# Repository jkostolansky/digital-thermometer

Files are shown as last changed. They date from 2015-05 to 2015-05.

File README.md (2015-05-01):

Digital Thermometer
===================

Digital Thermometer is an Arduino-based thermometer. It uses the DS18B20 1-Wire sensor.

Repository Contents
-------------------

* **/schematics**
    * **/schematics/eagle** - Eagle schematics and PCB layout
    * **/schematics/images** - Images of schematics and PCB layout
* **/digital_thermometer** - Arduino source code

The Beer-Ware License
---------------------

Juraj Kostolanský (@jkostolansky) wrote this file. As long as you retain this notice you can do whatever you want with this stuff. If we meet some day, and you think this stuff is worth it, you can buy me a beer in return.

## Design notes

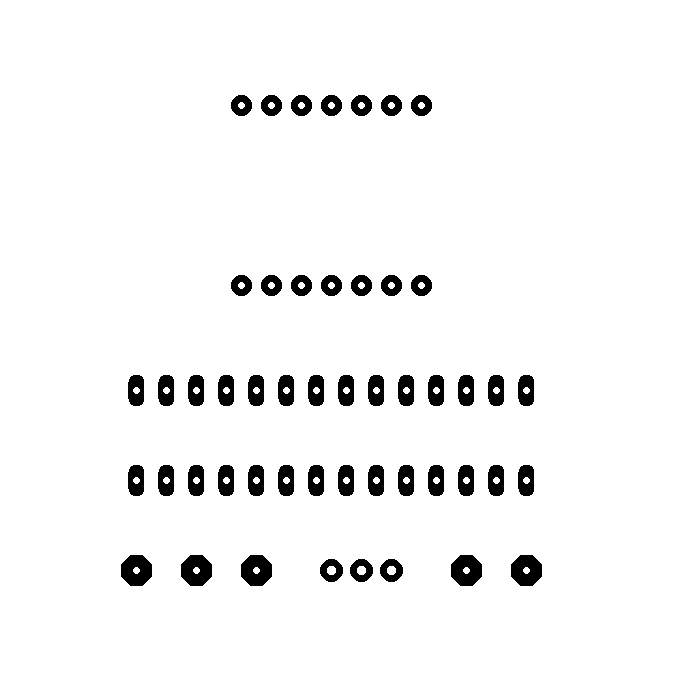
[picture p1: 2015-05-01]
schematics/images/pcb_mask.png

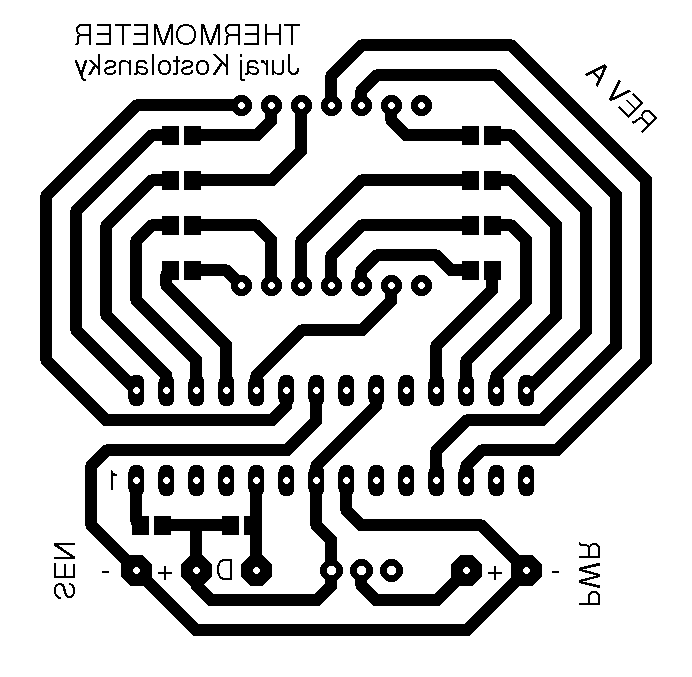
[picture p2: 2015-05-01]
schematics/images/pcb.png

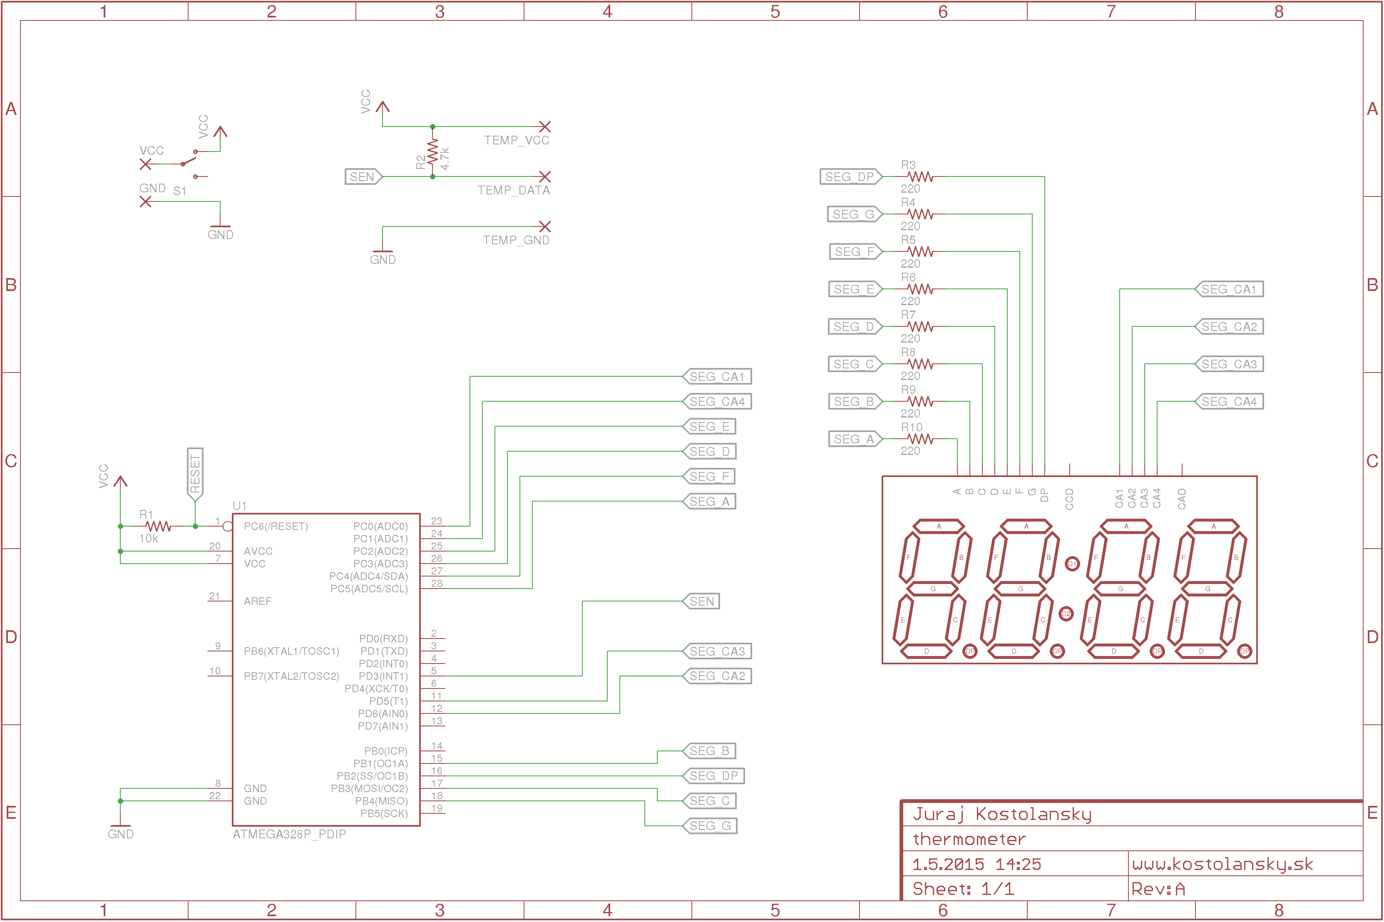
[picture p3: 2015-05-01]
schematics/images/schematic.png

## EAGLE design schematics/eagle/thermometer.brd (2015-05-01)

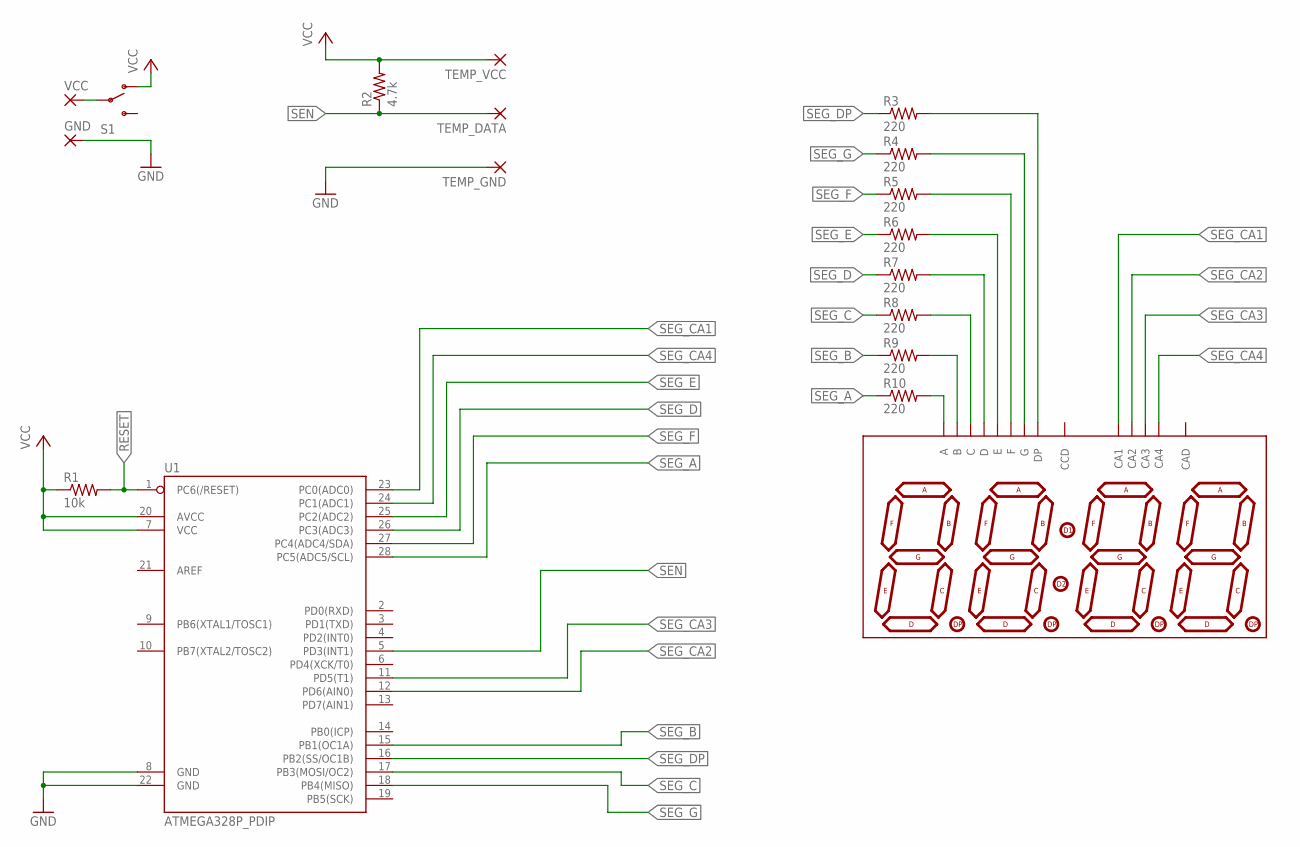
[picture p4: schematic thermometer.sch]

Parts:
GND: 2,54/0,8
R1: 10k; R0805
R2: 4.7k; R0805
R3, R4, R5, R6, R7, R8, R9, R10: 220; R0805
S1: SWITCH-SPDTPTH; SWITCH-SPDT
TEMP_DATA: 2,54/0,8
TEMP_GND: 2,54/0,8
TEMP_VCC: 2,54/0,8
U1: ATMEGA328P_PDIP; DIL28-3
U2: 5461BSDIP14; 5461BS
VCC: 2,54/0,8

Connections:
GND: GND.1, TEMP_GND.1, U1.8 (GND), U1.22 (GND)
unnamed: R10.2, U2.A
unnamed: R9.2, U2.B
unnamed: R7.2, U2.D
unnamed: R8.2, U2.C
unnamed: R6.2, U2.E
unnamed: R5.2, U2.F
unnamed: R4.2, U2.G
unnamed: R3.2, U2.DP
unnamed: S1.2, VCC.1
RESET: R1.2, U1.1 (PC6(/RESET))
SEG_A: R10.1, U1.28 (PC5(ADC5/SCL))
SEG_B: R9.1, U1.15 (PB1(OC1A))
SEG_C: R8.1, U1.17 (PB3(MOSI/OC2))
SEG_CA1: U1.23 (PC0(ADC0)), U2.CA1
SEG_CA2: U1.12 (PD6(AIN0)), U2.CA2
SEG_CA3: U1.11 (PD5(T1)), U2.CA3
SEG_CA4: U1.24 (PC1(ADC1)), U2.CA4
SEG_D: R7.1, U1.26 (PC3(ADC3))
SEG_DP: R3.1, U1.16 (PB2(SS/OC1B))
SEG_E: R6.1, U1.25 (PC2(ADC2))
SEG_F: R5.1, U1.27 (PC4(ADC4/SDA))
SEG_G: R4.1, U1.18 (PB4(MISO))
SEN: R2.1, TEMP_DATA.1, U1.5 (PD3(INT1))
VCC: R1.1, R2.2, S1.1 (O), TEMP_VCC.1, U1.7 (VCC), U1.20 (AVCC)

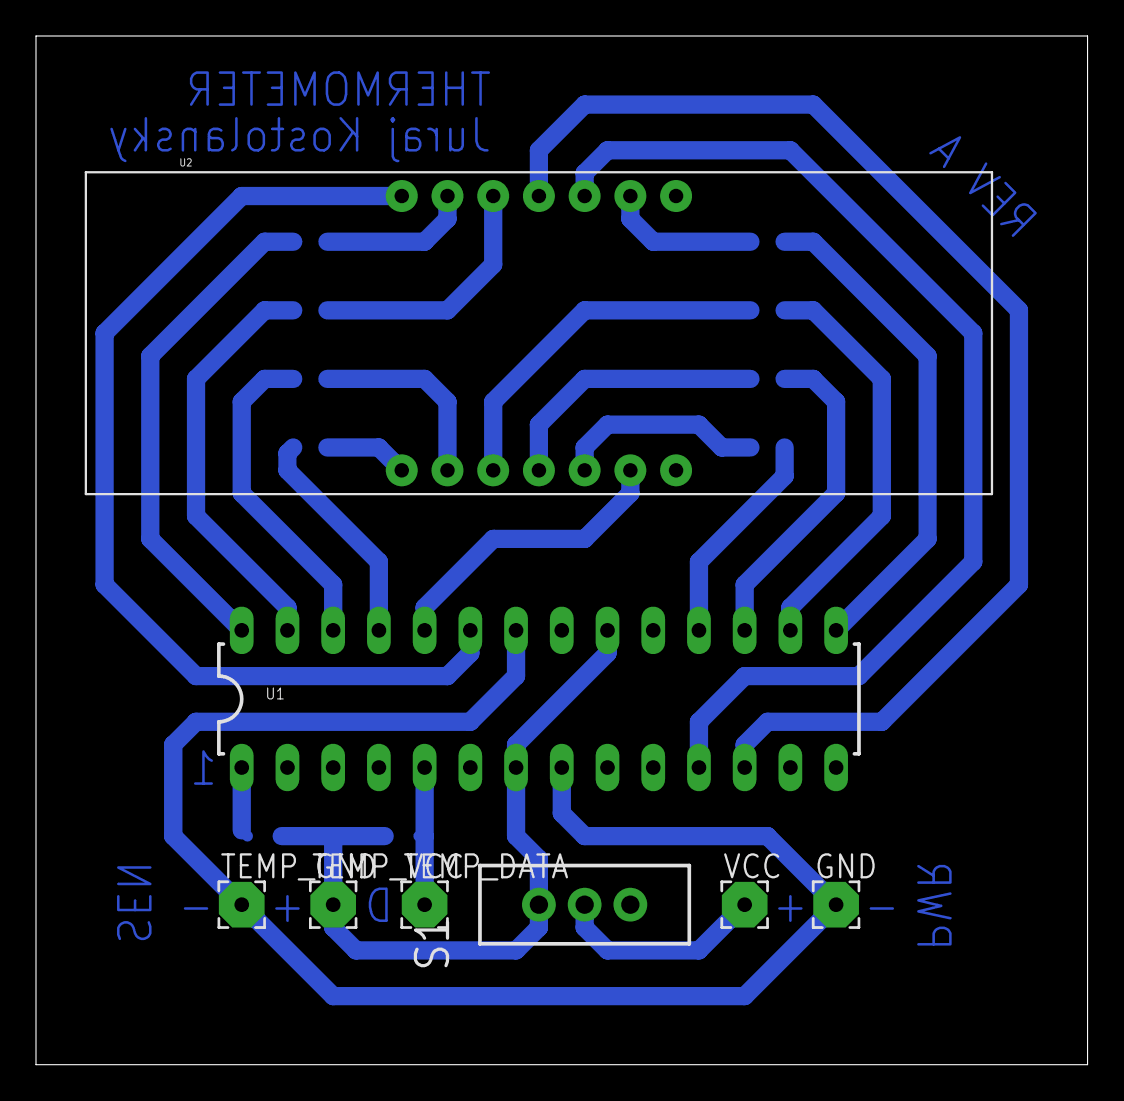
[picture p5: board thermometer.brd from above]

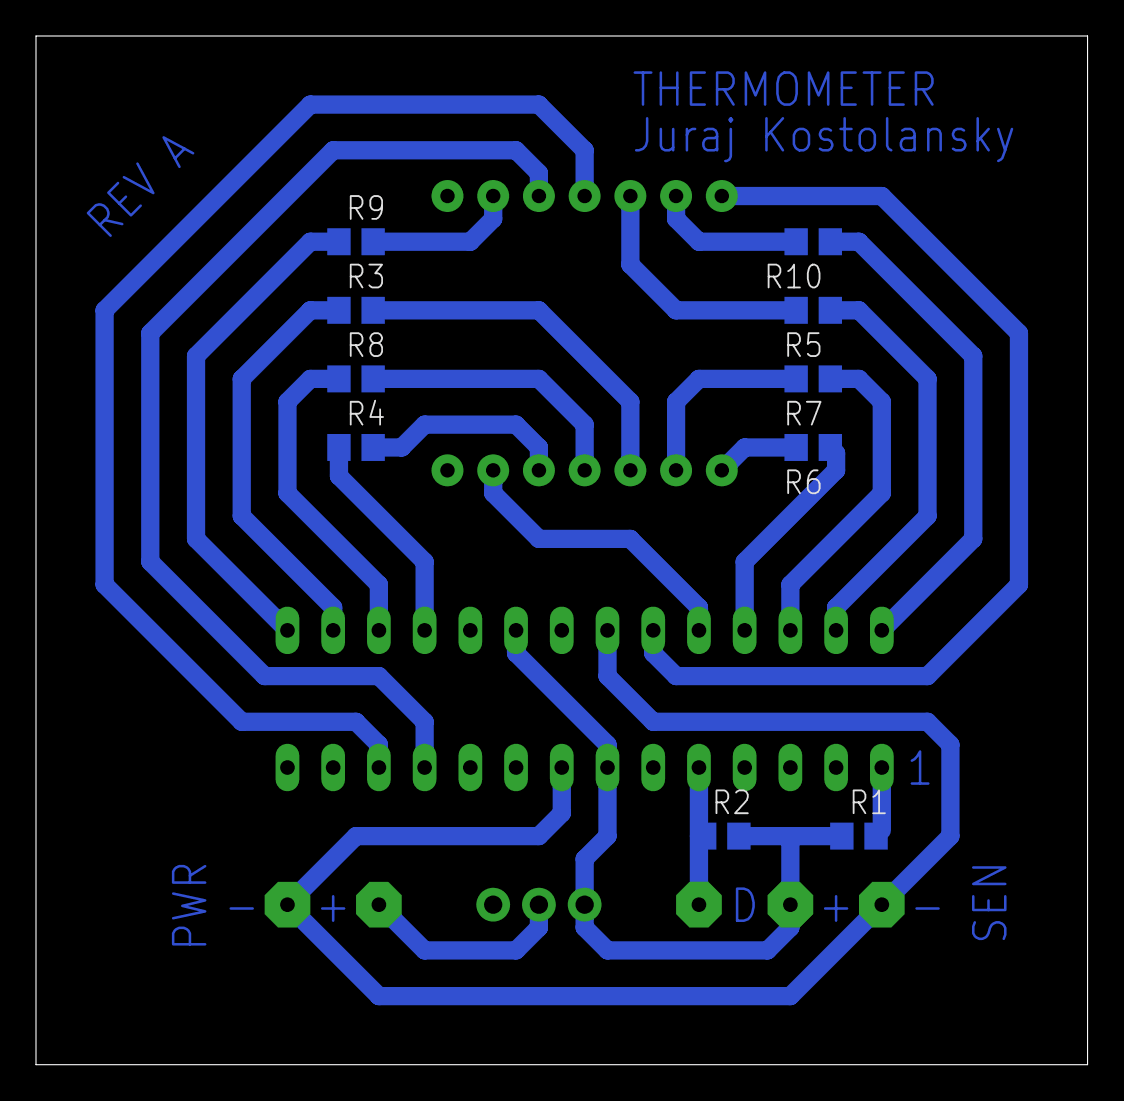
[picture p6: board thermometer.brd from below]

Board: 2 copper layers, 58.4 x 57.1 mm, 18 parts (10 on the bottom side), 25 nets.

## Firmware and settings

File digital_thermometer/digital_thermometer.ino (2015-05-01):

/*
  Digital Thermometer
  
  Reads temperature from a Dallas temperature sensor DS18B20
  and displays it on a 4-digit 7-segment display 5461BS
 
  by Juraj Kostolansky

 */

#include <OneWire.h>
#include <DallasTemperature.h>
#include <SevSeg.h>

// pinout
#define ONE_WIRE_BUS   3
#define SEG_A         19
#define SEG_B          9
#define SEG_C         11
#define SEG_D         17
#define SEG_E         16
#define SEG_F         18
#define SEG_G         12
#define SEG_DP        10
#define SEG_CA1       14
#define SEG_CA2        6
#define SEG_CA3        5
#define SEG_CA4       15

// settings
#define SEG_TYPE COMMON_ANODE
#define SEG_DIGITS 4
// resolution: 9 -> .5°C, 10 -> .25°C, 11 -> .125°C, 12 -> .0625°C
#define SIG_RESOLUTION 12
#define SEG_BRIGHTNESS 100

// One Wire and Dallas sensor setup
OneWire oneWire(ONE_WIRE_BUS); 
DallasTemperature sensors(&oneWire);
DeviceAddress tempDeviceAddress;

// SevSeg library setup
SevSeg screen;

// global variables
unsigned int temp_delay;
float temp;
int tempDigits;
unsigned long tempRequestEndTime;
char screenString[10];

void setup() {
  // start up the display
  screen.Begin(SEG_TYPE, SEG_DIGITS,
               SEG_CA1, SEG_CA2, SEG_CA3, SEG_CA4,
               SEG_A, SEG_B, SEG_C, SEG_D, SEG_E, SEG_F, SEG_G, SEG_DP);
  screen.SetBrightness(SEG_BRIGHTNESS);
  
  // start up the sensor
  sensors.begin();
  sensors.getAddress(tempDeviceAddress, 0);
  sensors.setWaitForConversion(false);
  sensors.setResolution(SIG_RESOLUTION);
  
  // request first temperature
  sensors.requestTemperatures();
  tempRequestEndTime = millis() + sensors.millisToWaitForConversion(SIG_RESOLUTION);
  // and wait for first temp to prevent false startup reading
  delay(sensors.millisToWaitForConversion(SIG_RESOLUTION));  
}

void loop() {
  // get temperature
  if(tempRequestEndTime < millis()) {
    temp = sensors.getTempC(tempDeviceAddress);
    sensors.requestTemperatures();
    tempRequestEndTime = millis() + sensors.millisToWaitForConversion(SIG_RESOLUTION);
  }  
  // round temp and convert to int (digits only)
  tempDigits = round(temp * 10.0);  
  // convert temperature to string
  if(temp >= 0) {
    sprintf(screenString, "%4d", tempDigits); 
  } else {
    // workaround for "-.5 or leading zeros" problem
    screenString[0] = '-';
    sprintf(&screenString[1], "%3d", tempDigits * -1);
  }  
  // and display it (one decimal place)
  screen.DisplayString(screenString, 4);
}

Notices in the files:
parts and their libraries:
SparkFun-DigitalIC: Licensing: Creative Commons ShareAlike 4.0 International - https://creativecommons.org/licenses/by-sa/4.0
